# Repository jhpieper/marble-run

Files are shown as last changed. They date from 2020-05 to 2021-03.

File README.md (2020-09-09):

# Marble Run
3D printable magnetic marble run modeled in openSCAD.

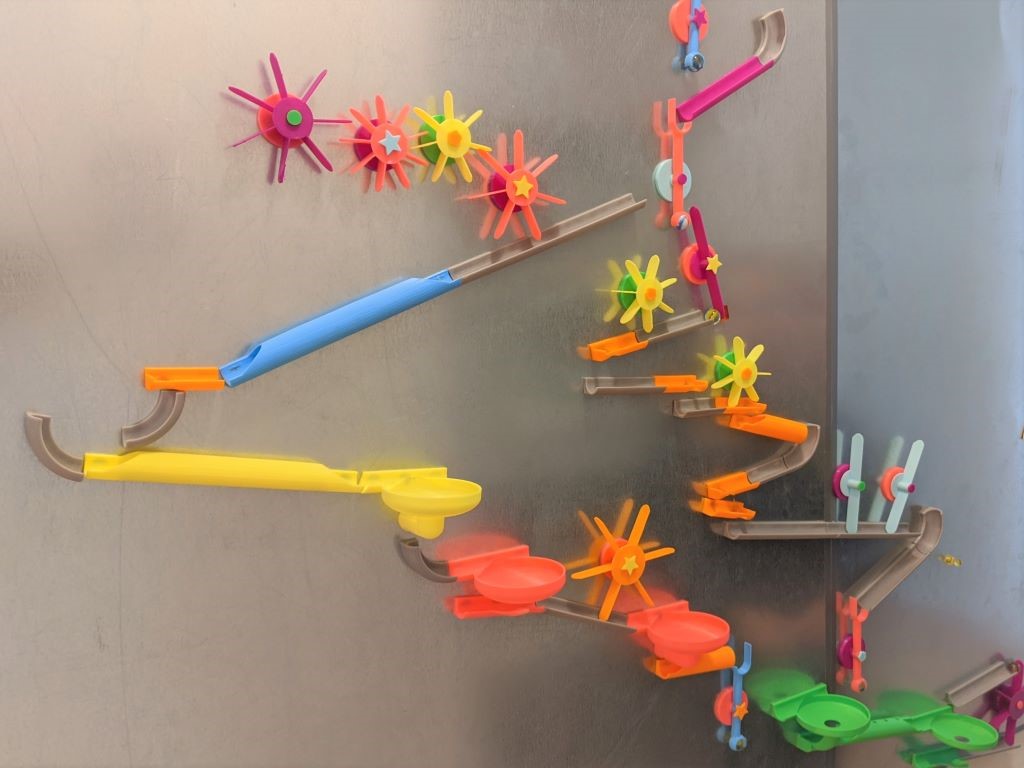
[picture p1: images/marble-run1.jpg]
Our marble run


A collection of marble run tracks that mount onto any magnetic surface.  
Make it your own by deciding which parts to print or even customizing them using the included openscad files!

## The Tracks
<table border=0 padding=3 width=100%>
<tr><td valign="top">

<h3>Straight</h3>
Just a straight run. Available in many lengths from 50mm to 200mm.
</td><td width=230px align="center">
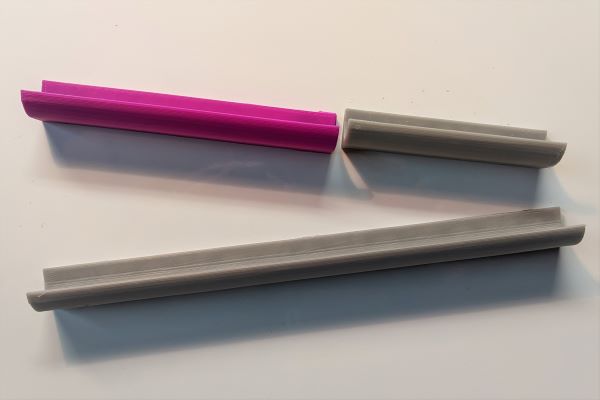
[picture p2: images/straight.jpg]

</td></tr><tr><td valign="top">

<h3>The Wave</h3>
This track makes things a bit more interesting. Print with supports.
</td><td align="center">
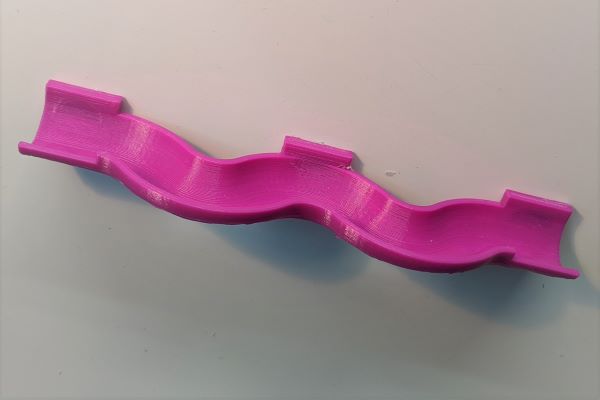
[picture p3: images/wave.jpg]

</td></tr><tr><td valign="top">

<h3>Curve</h3>
A 90 degree curved piece.  Great to catch a falling ball and getting it onto the next track.
</td><td align="center">
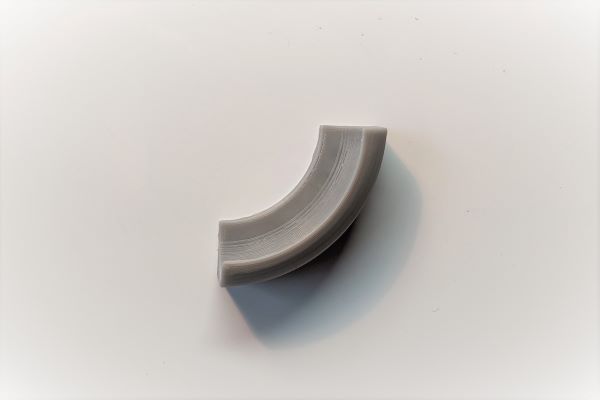
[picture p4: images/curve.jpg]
  
</td></tr><tr><td valign="top">

<h3>The Tunnel</h3>
A straight pipe that hides the ball.  Available in multiple lengths.
</td><td align="center">
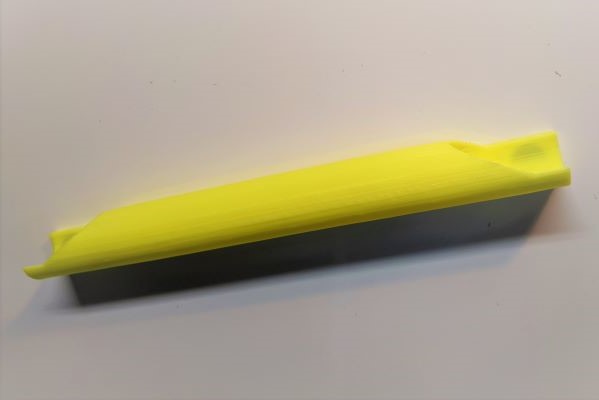
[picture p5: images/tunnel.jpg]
  
</td></tr><tr><td valign="top">

<h3>The Drop</h3>
A classic way to drop the ball onto the next track.
</td><td align="center">
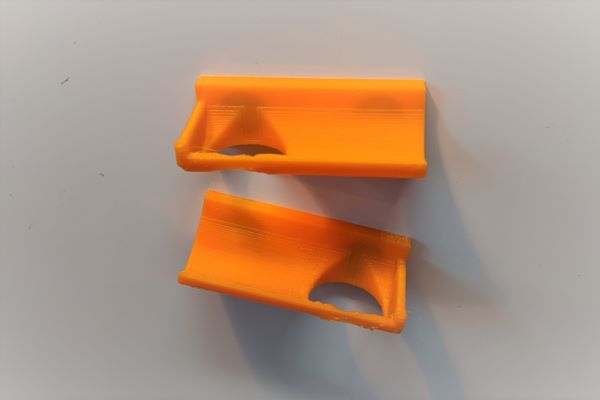
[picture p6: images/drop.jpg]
  
</td></tr><tr><td valign="top">

<h3>Lombard Street</h3>
A San Francisco landmark for your marble.  Print with supports.
</td><td align="center">
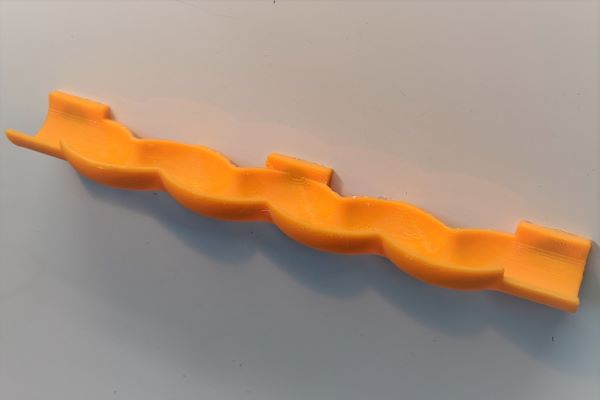
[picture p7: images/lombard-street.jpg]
  
</td></tr><tr><td valign="top">

<h3>The Wheel</h3>
Spins as the ball goes past.  Get creative and use it to launch another ball that is stored in the wheel.  Or kick a ball placed on a track above into action.

Available in various sizes and blade counts.  Some assembly required: wheel-\<-size\>-\<bladecount\> + wheel-base + lock-\<style\>.

Customize the look by using different colors for the parts.
</td><td align="center">
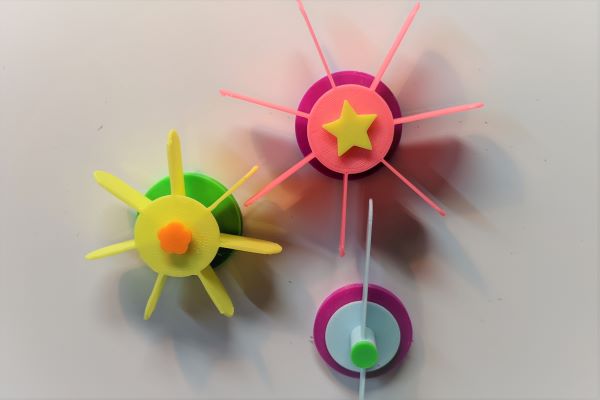
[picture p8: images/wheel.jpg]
  
</td></tr><tr><td valign="top">

<h3>The Pole</h3>
Catch a ball and vault it to the next track.

Assemble pole-\<left|right\> + pole-base + lock-\<style\>

Customize the look by using different colors for the parts.

The picture shows several design iterations.
</td><td align="center">
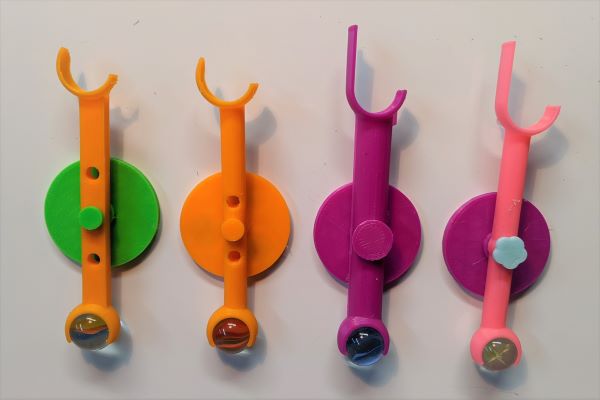
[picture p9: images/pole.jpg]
  
</td></tr><tr><td valign="top">

<h3>The Whirlpool!</h3>
The ball goes in circles until it drops through the center.  Mount level for best effect.
</td><td align="center">
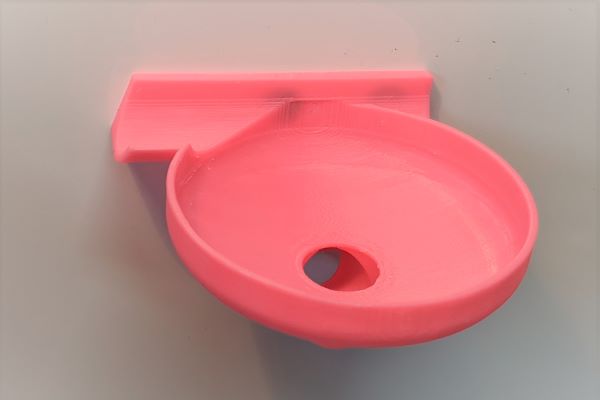
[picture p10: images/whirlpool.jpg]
  
</td></tr><tr><td valign="top">

<h3>The Looping</h3>
This one is tricky!  Mount it at the right angle, extend the incoming ramp and the marble will
successfully perform a looping.
</td><td align="center">
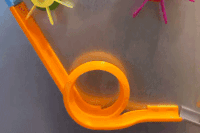
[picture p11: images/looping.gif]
  
</td></tr><tr><td valign="top">

<h3>Funnel</h3>
It's a funnel. 
</td><td align="center">
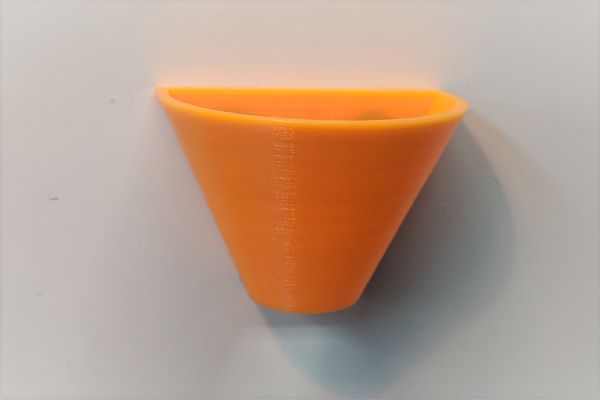
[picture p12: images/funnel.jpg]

</td></tr><tr><td valign="top">

<h3>Auto-Launcher</h3>
Releases one marble every couple of seconds.  See it on <a href="https://youtu.be/TCUJiLz-vXs">YouTube</a>.

Assemble auto-launcher + pole-base + lock-\<style\> 
</td><td align="center">
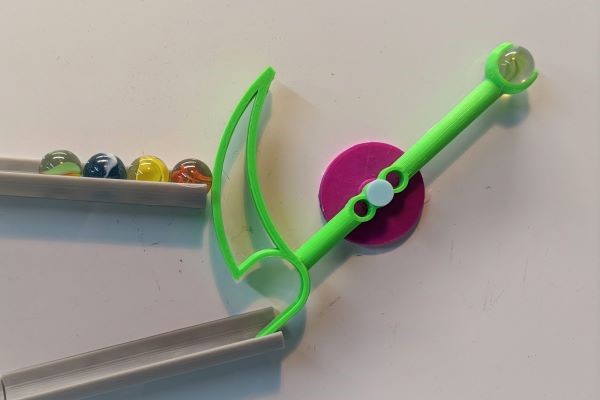
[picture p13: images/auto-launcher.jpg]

</td></tr><tr><td valign="top">
<h3>Flipflop</h3>
The flipflop diverts the marble left or right. 

Assemble flipflop + flipflop-base + lock-\<style\>
</td><td align="center">
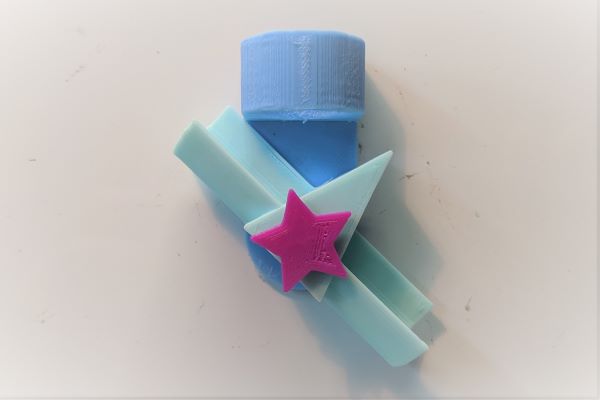
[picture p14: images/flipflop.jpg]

</td></tr><tr><td valign="top">

<h3>Tray</h3>
The tray is a great way to finish the run and to store extra marbles. 
</td><td align="center">
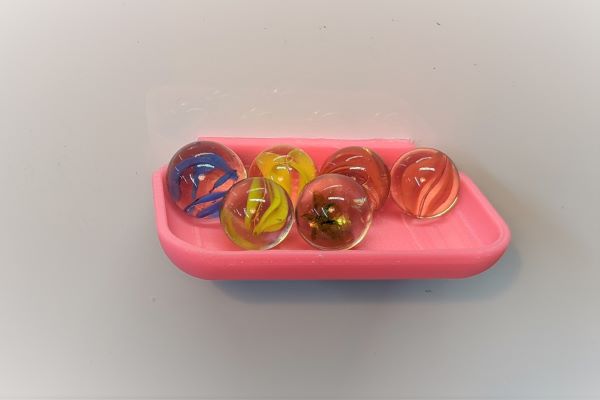
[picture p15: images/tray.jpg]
  
</td></tr>
</table>

## Magnets
All tracks are designed for round 10mm x 2mm magnets.  
They can easily be ordered from [Amazon](https://www.amazon.com/gp/product/B0753ZPBLQ/) or other retailers.

Each track needs at least two magnets, but many require three or even more.

The mounting holes were initially designed to be tight enough to just push the magnets in, 
but that turned out to be problematic.  It was difficult to get the magnets to be flat rather than pivoting.  Magnets would regularly fall out, etc.

In the end I switched to securing the magnets with hot glue.  The holes are slightly wider to easily allow the magnet to be pushed into the glue.  Hot glue is also excellent to make the back of the track less smooth if tracks slide on the board when marbles pass.  Just spread a thin layer of hotglue all along the back and let it cool.  The resulting surface has a nice grip.

## MIT License
Copyright (c) 2020 Jan Pieper (jhpieper.github@gmail.com)

This code is hosted at github.com/jhpieper/marble-run under the MIT license.
The 3D objects (STL files) are also hosted on thingiverse.com under
the Creative Commons Attribution 4.0 International (CC BY 4.0) license.

Permission is hereby granted, free of charge, to any person obtaining a copy
of this software and associated documentation files (the "Software"), to
deal in the Software without restriction, including without limitation the
rights to use, copy, modify, merge, publish, distribute, sublicense, and/or
sell copies of the Software, and to permit persons to whom the Software is
furnished to do so, subject to the following conditions:

The above copyright notice and this permission notice shall be included in
all copies or substantial portions of the Software.

THE SOFTWARE IS PROVIDED "AS IS", WITHOUT WARRANTY OF ANY KIND, EXPRESS OR
IMPLIED, INCLUDING BUT NOT LIMITED TO THE WARRANTIES OF MERCHANTABILITY,
FITNESS FOR A PARTICULAR PURPOSE AND NONINFRINGEMENT. IN NO EVENT SHALL THE
AUTHORS OR COPYRIGHT HOLDERS BE LIABLE FOR ANY CLAIM, DAMAGES OR OTHER
LIABILITY, WHETHER IN AN ACTION OF CONTRACT, TORT OR OTHERWISE, ARISING
FROM, OUT OF OR IN CONNECTION WITH THE SOFTWARE OR THE USE OR OTHER DEALINGS
IN THE SOFTWARE.

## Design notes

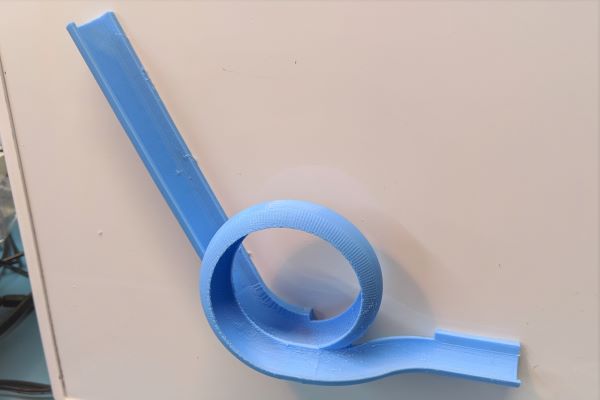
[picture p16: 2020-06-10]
images/looping.jpg

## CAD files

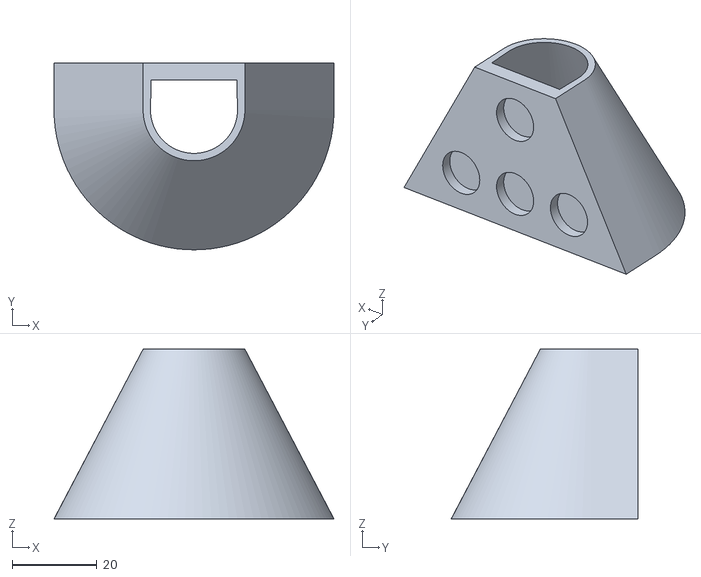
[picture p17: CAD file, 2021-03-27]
stl/funnel.stl
66.0 x 44.0 x 40.0

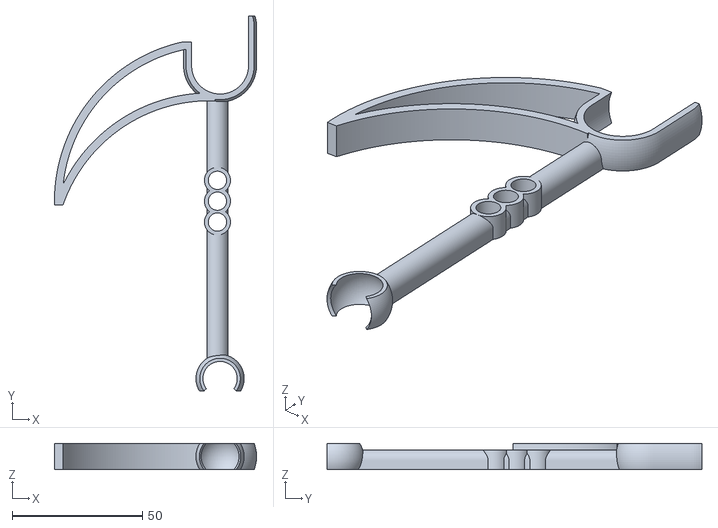
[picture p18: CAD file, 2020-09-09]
stl/auto-launcher-right.stl
77.5 x 143.8 x 10.0

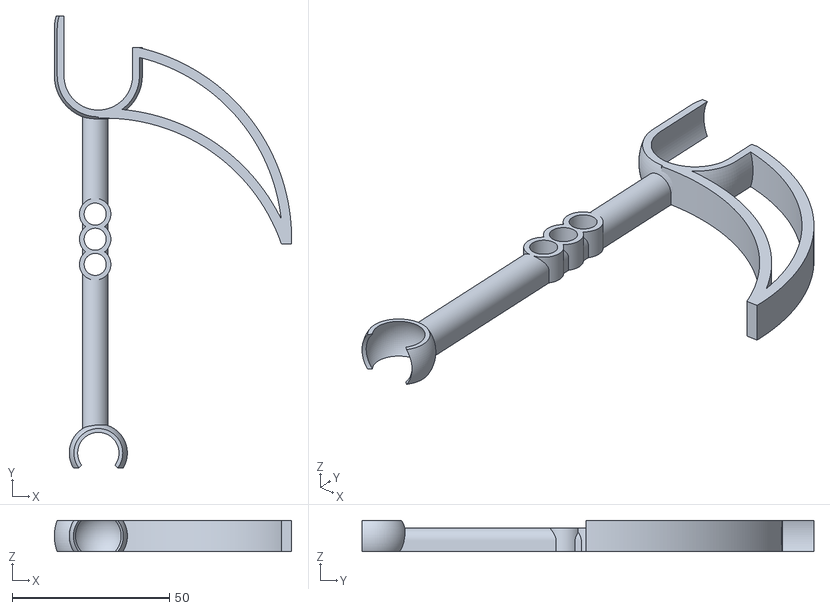
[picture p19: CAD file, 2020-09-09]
stl/auto-launcher-left.stl
75.5 x 143.8 x 10.0

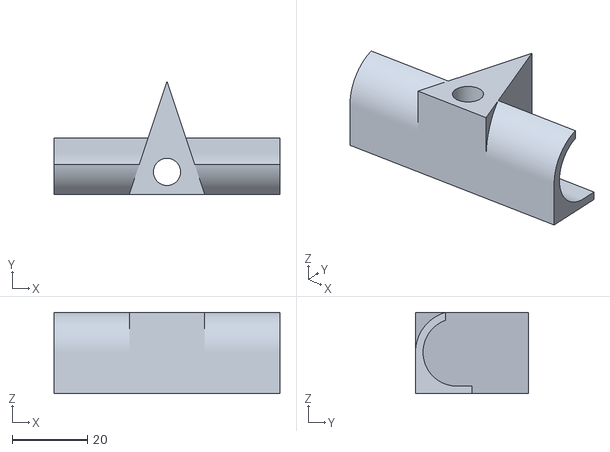
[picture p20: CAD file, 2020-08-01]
stl/flipflop.stl
60.0 x 30.0 x 21.6

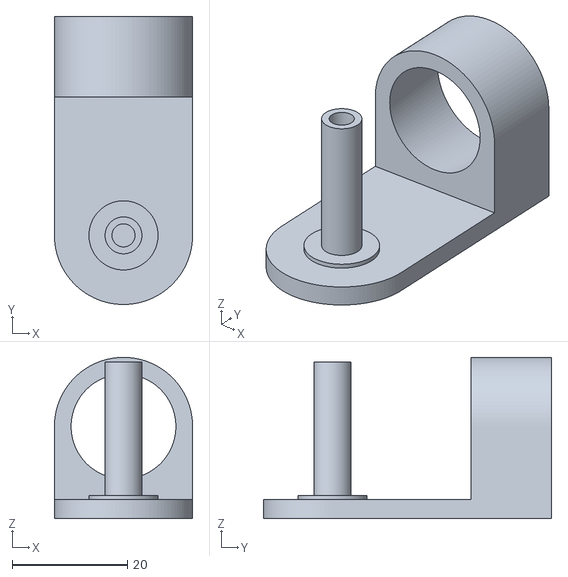
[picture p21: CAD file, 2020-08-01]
stl/flipflop-base.stl
24.0 x 50.0 x 28.0

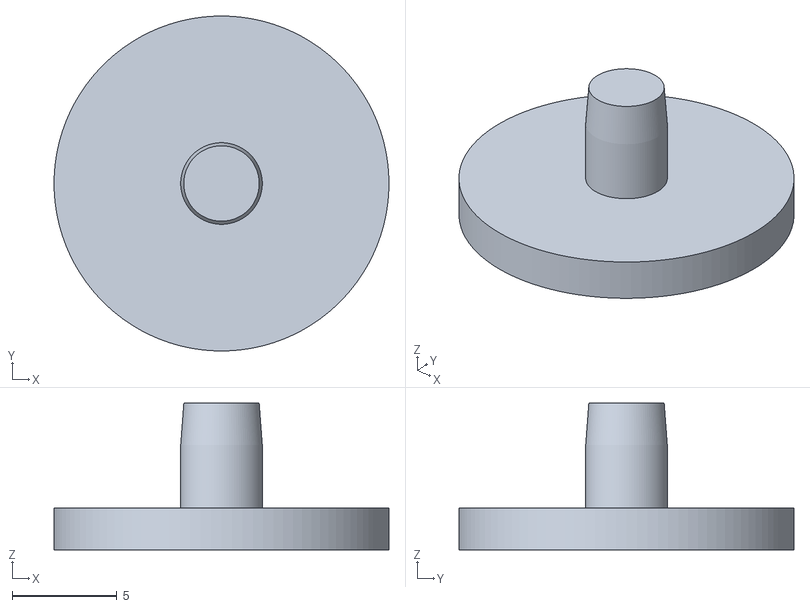
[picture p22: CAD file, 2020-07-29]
stl/lock-big-round.stl
16.0 x 16.0 x 7.00

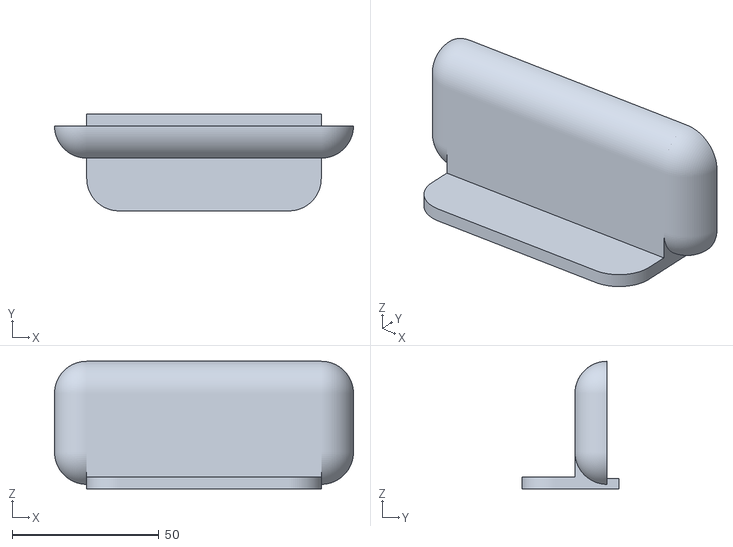
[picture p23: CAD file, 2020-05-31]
stl/tray-80.stl
102.0 x 33.0 x 43.5

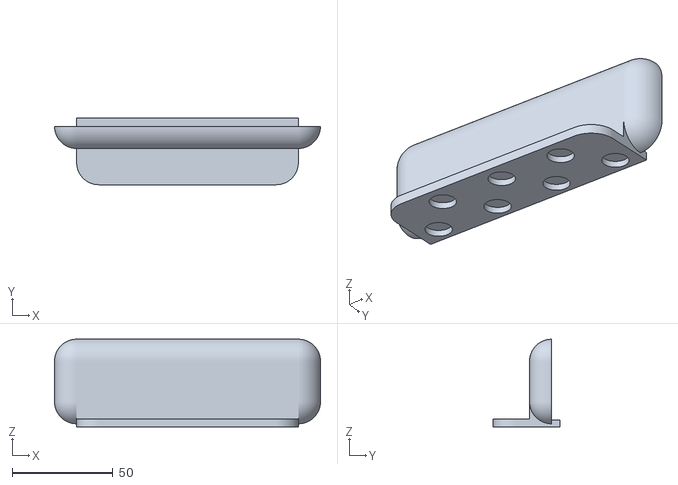
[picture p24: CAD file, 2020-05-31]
stl/tray-110.stl
132.0 x 33.0 x 43.5

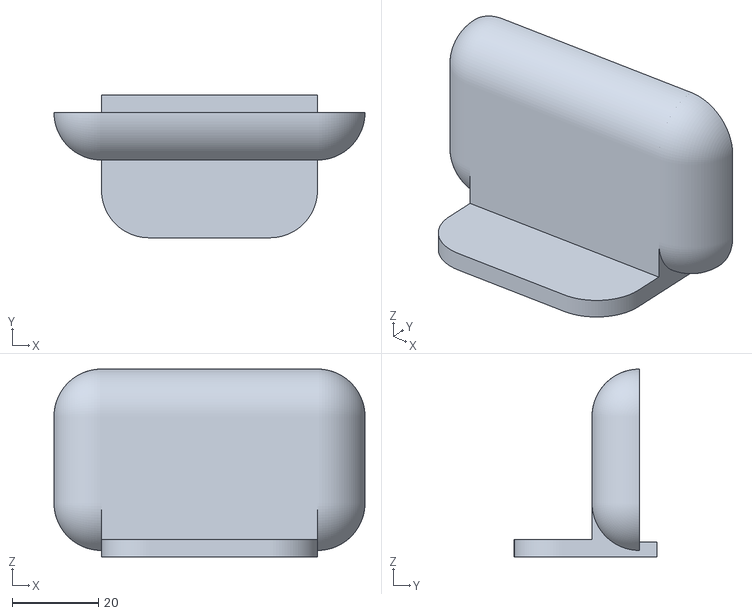
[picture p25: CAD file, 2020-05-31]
stl/tray-50.stl
72.0 x 33.0 x 43.5

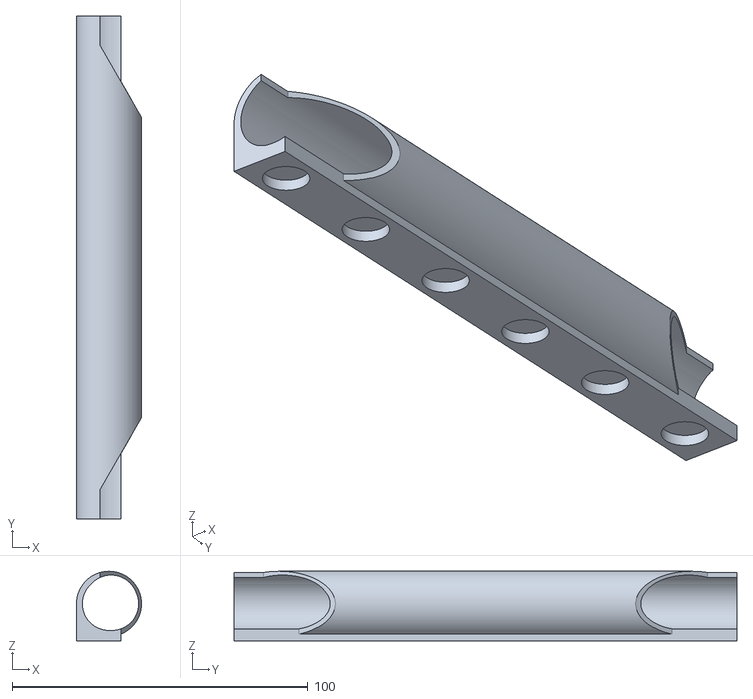
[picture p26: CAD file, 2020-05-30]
stl/tunnel-170.stl
22.0 x 170.0 x 23.5

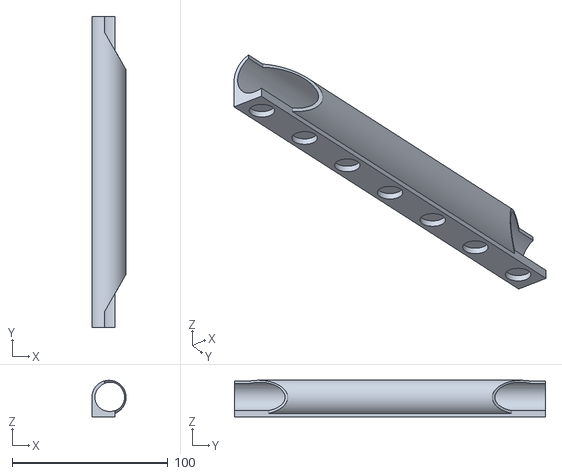
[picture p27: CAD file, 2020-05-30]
stl/tunnel-200.stl
22.0 x 200.0 x 23.5

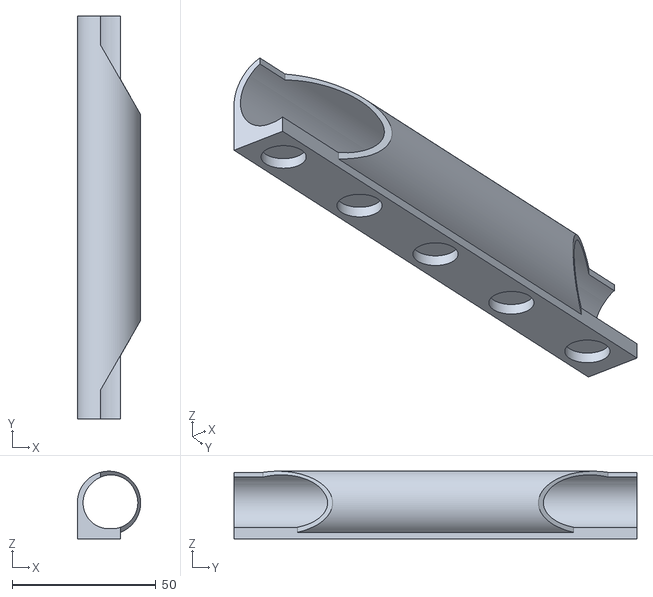
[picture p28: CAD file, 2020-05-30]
stl/tunnel-140.stl
22.0 x 140.0 x 23.5

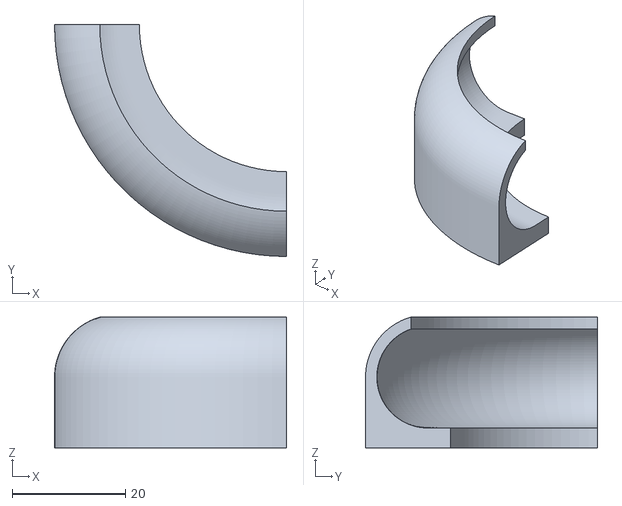
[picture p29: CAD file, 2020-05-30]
stl/curve.stl
41.0 x 41.0 x 23.1

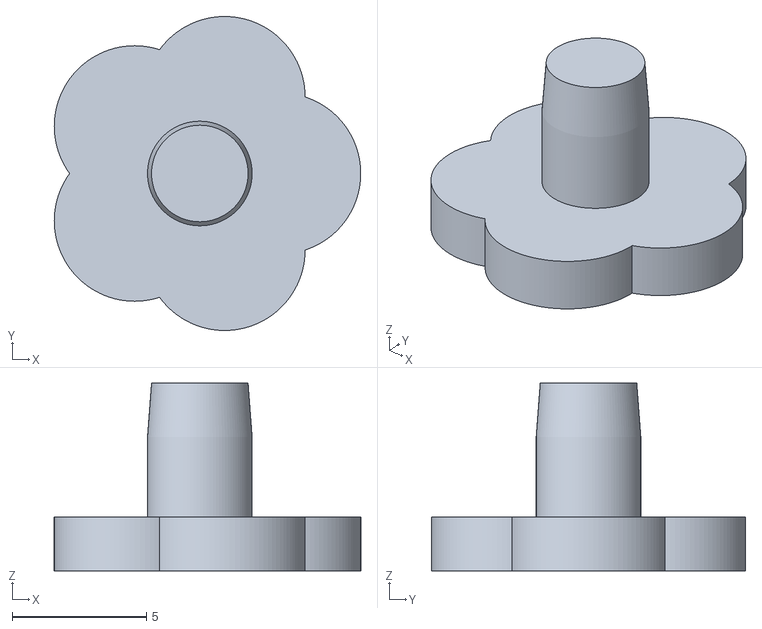
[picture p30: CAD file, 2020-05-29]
stl/lock-flower.stl
11.4 x 11.7 x 7.00

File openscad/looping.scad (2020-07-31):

// The Looping
//
// Copyright (c) 2020 Jan Pieper (jhpieper.github@gmail.com)
//
// This code is hosted at github.com/jhpieper/marble-run under the MIT license.
// The 3D objects (STL files) are also hosted on thingiverse.com under
// the Creative Commons Attribution 4.0 International (CC BY 4.0) license.
//
// Permission is hereby granted, free of charge, to any person obtaining a copy
// of this software and associated documentation files (the "Software"), to
// deal in the Software without restriction, including without limitation the
// rights to use, copy, modify, merge, publish, distribute, sublicense, and/or
// sell copies of the Software, and to permit persons to whom the Software is
// furnished to do so, subject to the following conditions:
//
// The above copyright notice and this permission notice shall be included in
// all copies or substantial portions of the Software.
//
// THE SOFTWARE IS PROVIDED "AS IS", WITHOUT WARRANTY OF ANY KIND, EXPRESS OR
// IMPLIED, INCLUDING BUT NOT LIMITED TO THE WARRANTIES OF MERCHANTABILITY,
// FITNESS FOR A PARTICULAR PURPOSE AND NONINFRINGEMENT. IN NO EVENT SHALL THE
// AUTHORS OR COPYRIGHT HOLDERS BE LIABLE FOR ANY CLAIM, DAMAGES OR OTHER
// LIABILITY, WHETHER IN AN ACTION OF CONTRACT, TORT OR OTHERWISE, ARISING
// FROM, OUT OF OR IN CONNECTION WITH THE SOFTWARE OR THE USE OR OTHER DEALINGS
// IN THE SOFTWARE.

// This model has a few issues, but it works.
// The loop is created by extruding the track in small steps
// and increasing Z for each step to bend it up. 
// The resulting model is expensive to render.  
// I set step=2 (degrees) to make it feasible. 
// 
// The outramp is stitched on through trial and error instead of 
// figuring out the actual math...
//
// The mesh has a bunch of errors.  I repaired the STL with
// https://service.netfabb.com/ 

magnet_radius = 5.5;  // Use 10x2mm magnets. 5.5 radius is good for hotglueing.  Use ~5 when just pushing magnets in.
$fn=100;

difference (){
  union(){
    step=2;  // degrees to extrude per step
    
    // Extrude small slices of the track as it rotates up.
    for(a=[0:step:420]) {
      rotate([0,0,a]) translate([0,0,a/17])rotate_extrude(angle=step, convexity=10) {
        translate ([-30,0,0]) rotate(a=[0,0,270]){
          if(a<70) {  // The beginning of the track backs against the wall.
            track();
            translate([9,-11,0]) square([30,15],0);
          } else {
            track2();
          }
        }
      }
    }

    // Lead in ramp
    translate([-30,140,0]) rotate([90,90,0]) difference() {
      linear_extrude(height=140, convexity=10) {
        track();
      }
      // magnets
      for (pos = [10:30:140]) {
        translate([9.8, -3.5, pos]) rotate(a=[0,90,0]) cylinder(h=3, r=magnet_radius);
      }
    }

    // Out ramp
    // short straight part after the loop
    translate([0,0,420/17]) rotate([90,0,420]) linear_extrude(height=15, convexity=10) {
      translate ([-30,0,0]) rotate(a=[0,0,270]){
        track2();
      }
    }
 
    pos=42; 
    translate([46,-61.3,42.2]) rotate([0,90,420]) mirror([1,0,0])   union() {
      // S-ramp back to the wall.
      rotate([0,0,-45]) {
        rotate_extrude(angle=45, convexity=10) translate ([-pos,0,0])   rotate([0,180,0]) track2();
        translate([-pos*2,0,0]) rotate_extrude(angle=45, convexity=10) translate ([pos,0,0]) rotate([0,180,0]) track2();
      }
    
      // End piece of the out ramp
      translate([-pos,-36,0]) rotate([90,0,180]) difference() {
        linear_extrude(height=40, convexity=10) {
          track();
          translate([9,-11,0]) square([4,15],0);
        }
        // magnets
        for (pos = [10:20:40]) {
          translate([9.8, -3.5, pos]) rotate(a=[0,90,0]) cylinder(h=3, r=magnet_radius);
        }
      }
    }
  }

  // Cut the wall side flat
  translate([-100,-100,-250 - 12.5])cube(250);
  // magnets
  for (i=[-55:35:-20]) {
  rotate([0,0,i]) translate([-10, -32, -9.8]) rotate(a=[0,180,90]) cylinder(h=3, r=magnet_radius);
  }  
}

module track() {
  difference() {
    union() {
      circle(11);
      translate([0,-11,0]) square(10);
    }
    circle(9);
    translate([-11,-3,0]) square(10);
    translate([-10,0,0]) square(22);
  }
  translate([9,-11,0]) square([3.5,15],0);
}

module track2() {
  difference() {
    union() {
      circle(11);
      //translate([0,-11,0]) square(10);
    }
    circle(9);
    translate([-11,-3,0]) square(10);
    translate([-10,0,0]) square(22);
  }
  //translate([9,-11,0]) square([3.5,15],0);
}

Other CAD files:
stl/straight-110.stl
stl/wheel-40-6.stl
stl/pole-base.stl
stl/wheel-30-5.stl
openscad/wheel-base.scad
openscad/wheel.scad
openscad/auto-launcher.scad
openscad/curve.scad
openscad/drop-left.scad
openscad/drop-right.scad
openscad/flipflop-base.scad
openscad/flipflop.scad
openscad/funnel.scad
openscad/lock-big-round.scad
openscad/lock-flower.scad
openscad/lock-round.scad
openscad/lock-star.scad
openscad/lombard-street.scad
openscad/pole-base.scad
openscad/pole-left.scad
openscad/pole-right.scad
openscad/straight-3d.scad
openscad/straight-extrude.scad
openscad/tray.scad
openscad/tunnel.scad
openscad/wave.scad
openscad/whirlpool.scad
stl/drop-left.stl
stl/drop-right.stl
stl/lock-round.stl
stl/lock-star.stl
stl/pole-left.stl
stl/pole-right.stl
stl/straight-140.stl
stl/straight-170.stl
stl/straight-200.stl
stl/straight-50.stl
stl/straight-80.stl
stl/wheel-30-6.stl
stl/wheel-40-2.stl
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

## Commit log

2020-05-29 First set of marble run components.
    [curve.scad, drop-left.scad, drop-right.scad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]
2020-05-29 Formatting and clean up.
    [curve.scad, drop-left.scad, drop-right.scad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]
2020-05-29 Generated .stl files
    [curve.stl, drop-left.stl, drop-right.stl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]
2020-05-30 Add pictures of each track to the documentation.
2020-05-30 Add third magnet hole to curve.
    [curve.scad]
2020-05-30 Adding 'The Tunnel'
    [tunnel-140.stl, tunnel-170.stl, tunnel-200.stl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]
2020-05-30 Add magnet mounting instructions
2020-05-31 Adding the Tray.
    [tray-110.stl, tray-50.stl, tray-80.stl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]
2020-06-03 The Looping.
    [looping.scad]
2020-06-08 Adding a funnel.
    [funnel.scad, funnel.stl]
2020-06-08 Adding the wave.
    [wave.scad]
2020-06-08 Lombard Street.
    [lombard-street.scad]
2020-07-29 Adding a larger round lock style.
    [lock-big-round.scad, lock-big-round.stl]
2020-07-31 MIT license notice
    [curve.scad, drop-left.scad, drop-right.scad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]
2020-09-09 Adding the auto-launcher that releases one marble every couple of seconds.
    [auto-launcher-left.stl, auto-launcher-right.stl, auto-launcher.scad]
2021-03-26 funnel: thicker back wall, bigger opening
    [funnel.scad, funnel.stl]
